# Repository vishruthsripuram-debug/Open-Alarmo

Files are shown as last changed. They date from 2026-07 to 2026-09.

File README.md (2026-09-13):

# Open-Alarmo
**Open Alarmo clock**

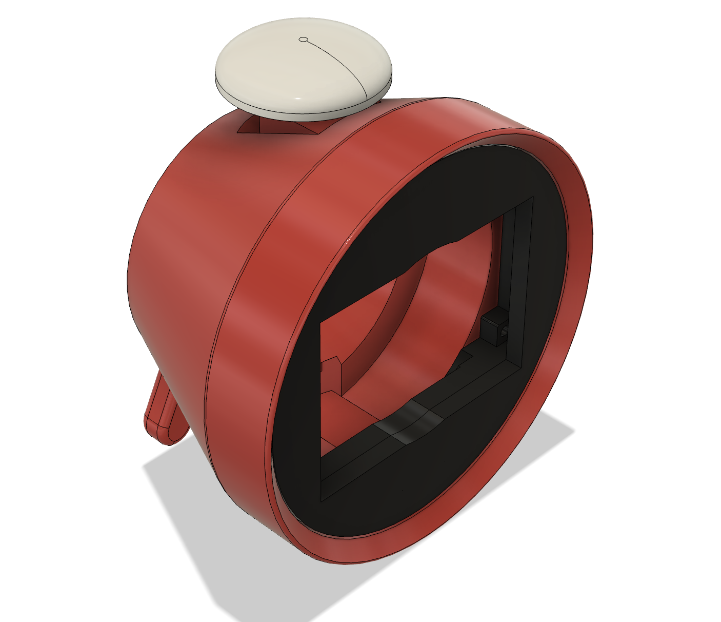
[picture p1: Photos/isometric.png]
Open Alarmo Front View

## design
I wanted to make an alarm clock that would wake me up at morn ing but also do it in a cool way and then an idea popped into my head one from 6 months ago when i saw the Nintendo Alarmo getting released. It was perfect, everything except that t was locked down, made by Nintendo and was too expensive. I set out to build one for a budget of just $20 USD.

It started with inspiration from the Nintendo alarm clock and then i decided to ditch the knob and instead have a web app to control it and set alarms for easier access, control and usability. I decided to keep the nice red design and the black front screen as it looked nice and didn't have any problems with fitting components.

## BOM

| Name | Cost (AUD) | Merchant | Purpose |
| :--- | :--- | :--- | :--- |
| CYD display | 16.79 | Aliexpress | To display the content |
| 1W speaker | 4.70 | aliexpress | to make sound |
| JST 1.25 10cm wire | 1.00 | aliexpress | To connect rotary encoder to CYD |
| KY - 040 rotary encoder | 3.36 | Aliexpress | To act as the dial for the display |
| **Total** | **$25.85** | | |

## Wiring Diagram

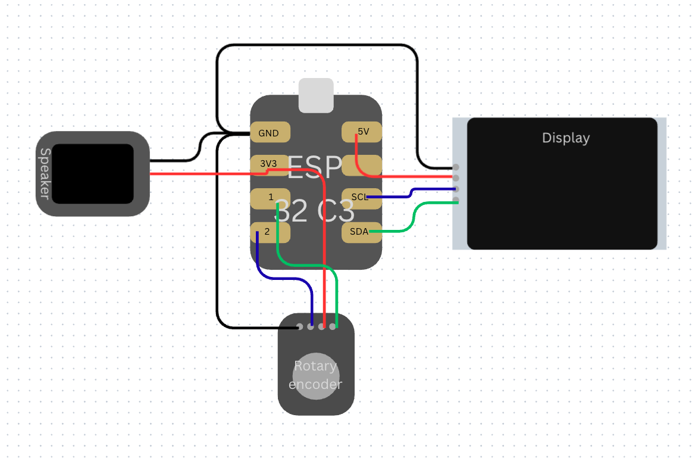
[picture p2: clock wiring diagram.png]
Clock Wiring Diagram


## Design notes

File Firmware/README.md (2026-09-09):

# Bedside Dial Alarm Clock — ESP32 firmware

A bedside alarm clock in the spirit of dedicated "turn the dial" alarm clocks:
big time display, a physical rotary dial on top for everything, and a
speaker for the wake-up chime. Built with an ESP32, a 2.8" SPI TFT
(ILI9341, 240×320), a rotary encoder, and a small speaker.

> Note on sound: the wake-up chime is an original arpeggio I wrote for this
> project, not a reproduction of any commercial device's copyrighted audio.
> Swap `ALARM_MELODY[]` in `src/SoundManager.cpp` for your own tune any time.

---

## 1. Hardware

| Part | Notes |
|---|---|
| ESP32 dev board | Any standard "ESP32-DevKitC"-style board |
| 2.8" SPI TFT, ILI9341 driver, 240×320 | The cheap "2.8 SPI TFT" modules on AliExpress/Amazon are almost all this chip |
| Rotary encoder w/ push button (e.g. EC11) | This is your "dial" — mount it on top of the enclosure |
| Small 8Ω speaker (0.5–1W) + NPN transistor (e.g. 2N2222) + 100–220Ω base resistor | Speaker driven from a PWM pin through a transistor switch |
| Optional: DS3231 RTC breakout | Keeps accurate time through power loss without WiFi. Strongly recommended — see §4 |

### Wiring

**TFT (SPI, ILI9341):**

| TFT pin | ESP32 GPIO |
|---|---|
| VCC | 3V3 |
| GND | GND |
| CS | 15 |
| RESET | 4 |
| DC (RS) | 2 |
| SDI (MOSI) | 23 |
| SCK | 18 |
| SDO (MISO) | 19 |
| LED (backlight) | 27 *(PWM-dimmed)* |

**Rotary encoder (the dial):**

| Encoder pin | ESP32 GPIO |
|---|---|
| A | 33 |
| B | 32 |
| Push button | 26 |
| + / GND | 3V3 / GND |

GPIO 33/32/26 are ordinary GPIOs so the firmware's internal pull-ups work
correctly. Deliberately **not** using GPIO34/35/36/39 for this — those are
input-only pins with no internal pull-up hardware on the ESP32, so
`INPUT_PULLUP` silently fails on them (a common first-build gotcha).

**Speaker (via transistor, simple PWM tone):**

```
GPIO25 --[220Ω]-- Base (2N2222)
Collector -- Speaker(-) 
Emitter -- GND
Speaker(+) -- 3V3
```

**DS3231 RTC (optional but recommended):** SDA → GPIO21, SCL → GPIO22, VCC
→ 3V3, GND → GND.

---

## 2. Software setup

This is a **PlatformIO** project (works in VS Code with the PlatformIO
extension, or via `pio` CLI). Just open the folder — dependencies
(`TFT_eSPI`, `RTClib`) install automatically from `platformio.ini`.

`platformio.ini` pins `platform = espressif32@6.9.0` on purpose — newer
platform releases pull in Arduino-ESP32 core 3.x, which replaced the
`ledcSetup`/`ledcAttachPin`/`ledcWriteTone` calls this firmware uses (for
the backlight PWM and speaker tone) with a different API. If you want to
use a newer core, update those calls in `UIManager::begin()` /
`SoundManager` to the new `ledcAttach(pin, freq, resBits)` /
`ledcWrite(pin, duty)` style first.

If you'd rather use the classic Arduino IDE:
1. Install the `TFT_eSPI` and `RTClib` libraries via Library Manager.
2. Copy the `build_flags` block from `platformio.ini` into your
   `TFT_eSPI/User_Setup.h` as `#define` lines instead (Arduino IDE has no
   `build_flags`, so TFT_eSPI needs its config edited directly in that
   case).
3. Rename `src/main.cpp` to `main.ino` inside a folder of the same name,
   and drop the other `src/*.cpp` + `include/*.h` files alongside it —
   Arduino IDE compiles every `.cpp`/`.h` in the sketch folder together.

### Before you flash

Edit `include/Config.h`:
- `WIFI_SSID` / `WIFI_PASSWORD` — used once at boot to fetch the correct
  time over NTP.
- `GMT_OFFSET_SEC` — currently set to `+10:00` (Sydney standard time).
  Change if you're elsewhere, or if you want DST handled automatically,
  set `DST_OFFSET_SEC` to `3600` during daylight saving.
- `USE_DS3231` — leave at `1` if you wired the RTC module; set to `0` if
  you didn't (the clock will then rely on NTP-synced internal time and
  will lose the correct time on power loss until it reconnects to WiFi).

---

## 3. Using it

**Clock face (home screen):**
- **Turn the dial** → jumps into the Alarms list.
- **Press the dial** → opens the main Menu.

**Main Menu** (New Alarm / Alarms / Brightness / Back):
- Turn to highlight, press to select, hold to go back.

**Alarm list:**
- Turn to highlight an alarm, **press to edit it**, **hold to delete it**.

**Editing an alarm:**
- Turn the dial to change the highlighted field's value (hour → minute →
  repeat → enabled, cycling on each press).
- **Press** moves to the next field.
- **Hold** saves and returns to the list, from any field — so there's no
  separate "Save" button you can accidentally click past.
- The "repeat" field cycles: Once → Everyday → Weekdays → Weekends.

**Brightness screen:** turn to adjust, press or hold to save.

**When an alarm rings:**
- **Turn the dial** (either direction) → snoozes for 9 minutes — this
  mirrors the "twist to snooze" feel of dedicated bedside dial clocks.
- **Press (or hold)** → dismisses it completely.
- Auto-dismisses after 10 minutes if left unattended (see
  `ALARM_RING_TIMEOUT_MIN` in `Config.h`).

Alarms, once set, persist across power loss (stored in flash via
`Preferences`/NVS) — you don't need WiFi or the RTC battery for the
*alarm list* to survive a reboot, only for the *current time* to.

---

## 4. Notes & things you'll likely want to tweak

- **Screen mirrored/rotated wrong?** Change `_tft.setRotation(1)` in
  `UIManager::begin()` (0–3) until it looks right for your enclosure
  orientation.
- **Speaker too quiet/harsh?** `SPEAKER_PIN`'s PWM "tone" through a bare
  transistor is a simple square-wave beeper, not a proper audio amp — for
  actually good speaker quality, swap in a MAX98357A I2S amp module and
  replace `SoundManager`'s `ledcWriteTone` calls with an I2S DAC output.
  The rest of the firmware doesn't care how `SoundManager` makes noise.
- **No DS3231 / don't want to enter WiFi credentials?** The internal
  ESP32 RTC drifts a few seconds a day and has no battery backup — fine
  for a plugged-in clock, but you'll want periodic NTP resync (the
  scaffolding for that is already in `TimeManager::loop()`, just don't
  disconnect WiFi at the end of `TimeManager::begin()` if you want it kept
  alive).
- **Custom per-day repeat schedules** (e.g. "Mon/Wed/Fri only") aren't in
  the UI yet — the data model (`Alarm::daysMask`, one bit per weekday)
  already supports it; `cycleRepeatPreset()` in `main.cpp` only cycles
  through 4 common presets for simplicity. Easy to extend into a
  day-by-day toggle screen if you want it.

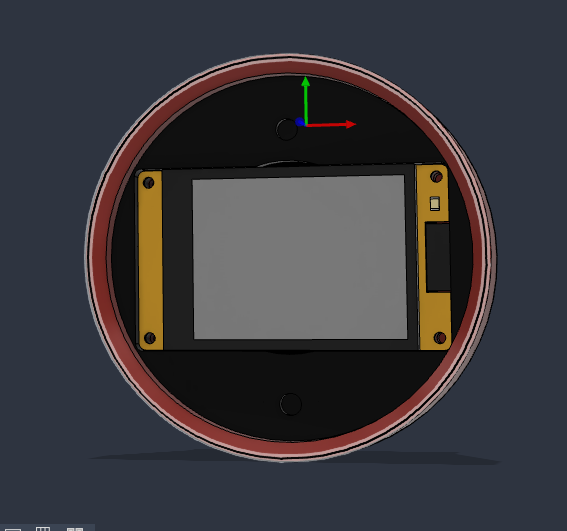
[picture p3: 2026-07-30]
Photos/Front view withoutcover.png

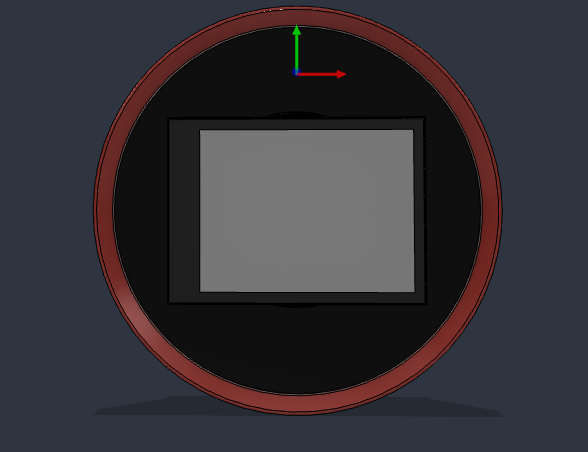
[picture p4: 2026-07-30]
Photos/front_view.png

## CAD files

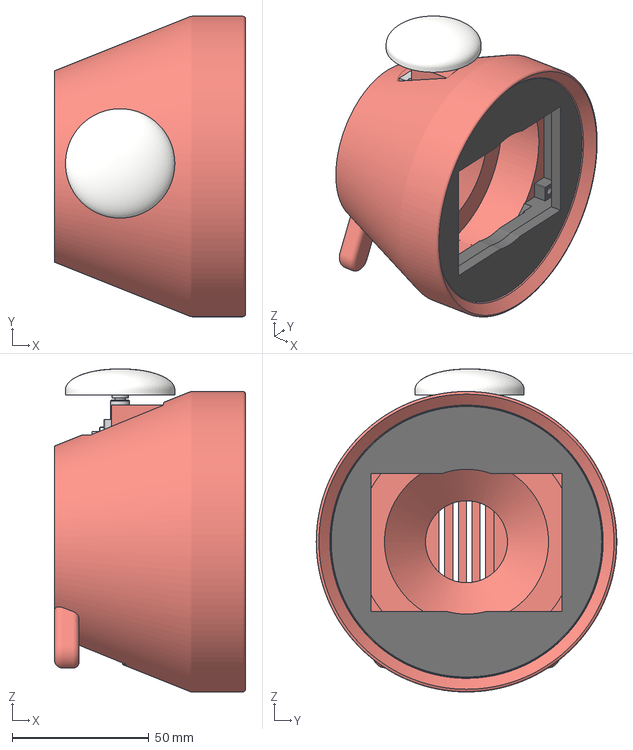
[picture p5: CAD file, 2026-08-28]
CAD files/Print.3mf
70.0 x 110.0 x 118.2 mm

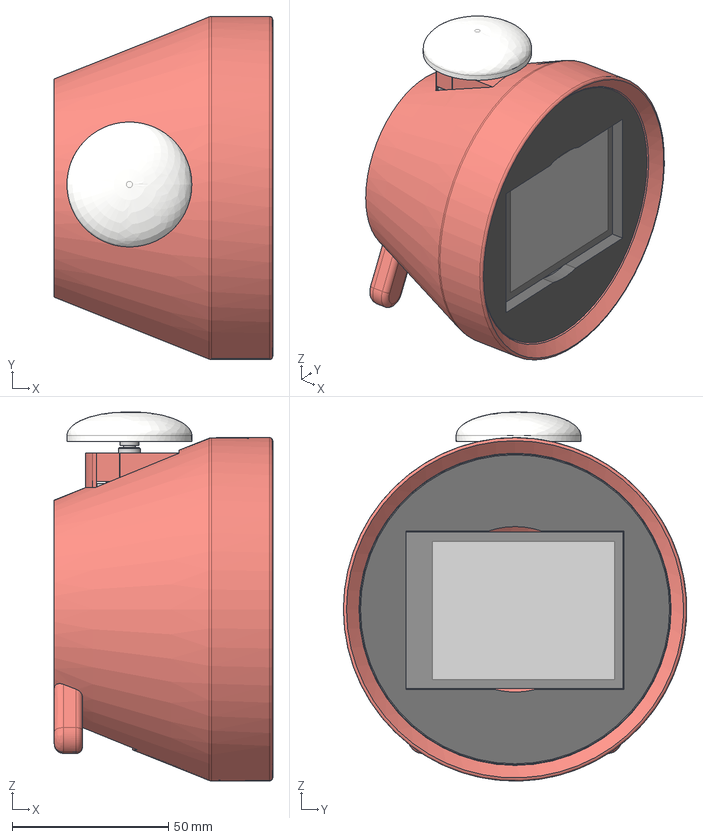
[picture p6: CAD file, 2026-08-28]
CAD files/Alarmo.step
70.0 x 110.0 x 118.2 mm
screen cover
rotary holder
10mm connector x 3
Spkr Connector
switch x 2
Micro SD Card
ESP32 WROOM
Micro USB 5 Pins, Right Angle SMT v1
LDR 21
Encoder KY-040
Rotary dial
Speaker cover plate

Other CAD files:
CAD files/Alarmo.3mf
CAD files/Alarmo.f3z

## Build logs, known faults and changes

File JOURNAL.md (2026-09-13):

---
title: "Open-Alarmo"
author: "Vishruth-S"
description: "An open source easy to build Alarm clock"
created_at: "2026-07-23"
---
# July 24: Planning project
**I started planning my project**
I wanted to make an alarm clock that would wake me up at morn ing but also do it in a cool way and then an idea popped into my head one from 6 months ago when i saw the Nintendo Alarmo getting released. It was perfect, everything except that t was locked down, made by Nintendo and was too expensive. I set out to build one for a budget of just $20 USD.

It started with inspiration from the Nintendo alarm clock and then i decided to ditch the knob and instead have a web app to control it and set alarms for easier access, control and usability. I decided to keep the nice red design and the black front screen as it looked nice and didn't have any problems with fitting components.


**Total time spent: 2.5 hours**

# July 24: CAD
I recorded my CAD time using Hackatime In this Cad session i designed and started to build the main frame of the clock it has a similar concave barrel shape but is more curved at the ends to offer a slightly nicer aesthetic. I decided to build it in 2 parts, the main body and the screen holder, the screen holder was by far the most complex part about the design, first i had to design it to fit smoothly without too many bumps and then i had to figure out a way to attach it to the main body. I originally though about screws but realized that screws may protrude outside of the main body and look ugly so i decided to design a twist lock mechanism using 2 fingers that twist into the main body. this removes the need fro screws and simplifies the assembly.
Inside view

**Total time spent: 4 hours**

# July 25: Shopping for components
Went shopping for the components
I found a rotary encoder that would connect to the CYD via a jst connector

I found everything on Aliexpress as it was cheapest and found the versions that had models available on Grabcad so design would be easier.

The updated BOM
also updated on Github readme

| Name | Cost (AUD) | Merchant | Purpose |
| :--- | :--- | :--- | :--- |
| CYD display | 16.79 | Aliexpress | To display the content |
| 1W speaker | 4.70 | aliexpress | to make sound |
| JST 1.25 10cm wire | 1.00 | Aliexpress | To connect rotary encoder to CYD |
| KY - 040 rotary encoder | 3.36 | Aliexpress | To act as the dial for the display |
| **Total** | **$25.85** | | |

Screenshot 2026-07-29 at 12 32 48 PM

**Total time spent: 3 hours**

# July 27: Redesign for CYD
I changed the design to accommodate a 2.8" touchscreen also more commonly known as the CYD which is a readily available, no solder low profile alternative tp using a TFT display and separate ESP 32 board. I removed the old twist lock mechanism in favor of the good old simple m3 screw which fits better into the design and is cleaner to look at, the front cover plate not has 2 options to attach. The first is press fit where you press fit it onto the display and the second is magnets, magnets are the preferred route but are more expensive so i decided to include a simpler alternative.
Front view withoutcover

**Total time spent: 5 hours**

# July 30: CAD
I added the mount for the rotary encoder and developed the front magnetic cover for the screen. The front magnetic cover is going to be black PLA to blend into the screen when it is turned off. When adding the front cover plate i had to decide what method of attachment i want to use, i wanted it to be easily removable for future upgrades and repairs but also wanted it to be stable and strong. Eventually after some thinking and trying out twist lock ideas i decided on using some strong 6x3 neodymium magnets fairly priced at just 33 C per magnet and only needing 2 would add only 66 cents to the project. After i finished back i went back to remedy my previous failure of a design for the rotary encoder mount, it was clunky, ugly and didn't match at all, so i decided to change it. I first deleted all of the old things in the timeline and restarted with a blank slate, i made an offset plane and extruded a rectangle onto it to create the platform and base. off of this platform i made some forms that would hold it in place and added a screw hole. The whole board just slides in and connects using a JST connector on the back of the CYD which i left a space for on the disc that is inserted into the main body. I then positioned the board and designed the back plate so then it would match perfectly and slide into the grommett there previously.
magnet
Without screen cover
Screenshot 2026-07-30 at 6 12 59 PM

**Total time spent: 3 hours**

# July 31: CAD
I designed the rotary dial cap, this is similar to the dial used to control the Nintendo Alarmo, although my variant will be touchscreen. The dial can be used to set alarms, timers and other time related activities, the dial can also be used to play games on the clock, it is a fun feature similar to the playdate. I had to figure out how to use a different type of filet, an asymmetrical fillet to get the desired shape. The clock design is now almost complete the last remaining feature is the speaker hole and the haptic motor for a satisfying feel everytime the wheel is turned.

Front view
Rotary dial
rotary encoder

**Total time spent: 3 hours**

# July 31: CAD: adding speaker grille and expanding USB port
I added the final touch which was the space for the speaker on the back of the device. The USB port expansion was a simple sketch and cut of the main body. The speaker grille is removable and vertical which i thought looked nice.
Speaker hole
**Total time spent: 1.5 hours**

# 09/9/2026 - I developed the code and editing software for the macropad

**Time spent:** 1.5h
I used claude to vibecode the firmware for the clock. This is just a sample firmware so i made it not apply to any pins yet however soon i can add the pins once I buy all the components and start building.
The clock has multiple files can have images uploaded to it and can ring an alarm to wake someone up, i also added animated icons and made a webpage for the same purpose.
work screenshot

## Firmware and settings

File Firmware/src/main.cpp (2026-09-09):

// =====================================================================
//  Nintendo-Alarmo-style ESP32 alarm clock
//
//  Hardware: ESP32 dev board + 2.8" SPI TFT (ILI9341) + small speaker
//            driven through a transistor + a rotary encoder w/ push
//            button mounted on top as the main control dial.
//
//  Interaction model (mirrors the "turn the dial" feel of a dedicated
//  bedside alarm clock):
//    Clock face  : rotate -> jump into Alarm List | click -> Main Menu
//    Main Menu   : rotate -> highlight | click -> select | hold -> back
//    Alarm List  : rotate -> highlight | click -> edit | hold -> delete
//    Edit Alarm  : rotate -> change focused field | click -> next field
//                  hold -> save & return to list
//    Brightness  : rotate -> adjust | click/hold -> save & back
//    Ringing     : rotate (either way) -> snooze | click/hold -> dismiss
//
//  See README.md for wiring and library setup.
// =====================================================================
#include <Arduino.h>
#include "Config.h"
#include "UIManager.h"
#include "RotaryInput.h"
#include "SoundManager.h"
#include "AlarmManager.h"
#include "TimeManager.h"

// ---------------------------------------------------------------------
// globals
// ---------------------------------------------------------------------
UIManager     ui;
RotaryInput   dial;
SoundManager  sound;
AlarmManager  alarms;
TimeManager   clock_;

enum class AppState { CLOCK, MENU, ALARM_LIST, EDIT_ALARM, BRIGHTNESS, RINGING };
AppState state = AppState::CLOCK;

MenuItem  menuSelect = MenuItem::NEW_ALARM;
uint8_t   alarmListSelect = 0;

EditField editField = EditField::HOUR;
uint8_t   editingIndex = 0;
bool      isNewAlarm = false;

int       ringingIndex = -1;   // index into alarms[], or -1 if snooze-triggered w/ no stable index
Alarm     ringingAlarmSnapshot;
uint32_t  ringingAnimStart = 0;

uint8_t   pendingBrightness = DEFAULT_BRIGHTNESS;

uint32_t  lastUiTickMs = 0;

// ---------------------------------------------------------------------
// helpers
// ---------------------------------------------------------------------
static const char *repeatLabelFor(uint8_t mask) {
    if (mask == 0)          return "Once";
    if (mask == 0x7F)       return "Everyday";
    if (mask == 0b0111110)  return "Weekdays";
    if (mask == 0b1000001)  return "Weekends";
    return "Custom";
}

// Finds the soonest upcoming enabled alarm (today or later this week) for
// the clock-face "Next" chip. Returns false if none are enabled.
static bool findNextAlarm(uint8_t nowWday, uint8_t nowH, uint8_t nowM,
                           uint8_t &outH, uint8_t &outM, const char *&outRepeat) {
    int bestDelta = INT32_MAX;
    int bestIdx = -1;
    int nowMin = nowH * 60 + nowM;

    for (uint8_t i = 0; i < alarms.count(); i++) {
        Alarm &a = alarms.at(i);
        if (!a.enabled) continue;
        int alarmMin = a.hour * 60 + a.minute;

        for (int d = 0; d < 7; d++) {
            uint8_t wday = (nowWday + d) % 7;
            // one-off (daysMask == 0) alarms only ever count for "today, if still ahead"
            if (a.daysMask == 0) {
                if (d > 0) continue;
            } else if (!(a.daysMask & (1 << wday))) {
                continue;
            }

            int delta = d * 1440 + alarmMin - nowMin;
            if (delta < 0) continue;
            if (delta < bestDelta) {
                bestDelta = delta;
                bestIdx = i;
            }
        }
    }

    if (bestIdx < 0) return false;
    outH = alarms.at(bestIdx).hour;
    outM = alarms.at(bestIdx).minute;
    outRepeat = repeatLabelFor(alarms.at(bestIdx).daysMask);
    return true;
}

static void enterRinging(int idx, const Alarm &snapshot) {
    state = AppState::RINGING;
    ringingIndex = idx;
    ringingAlarmSnapshot = snapshot;
    ringingAnimStart = millis();
    sound.startAlarm();
    ui.forceFullRedraw();
}

static void cycleRepeatPreset(Alarm &a, int direction) {
    static const uint8_t presets[] = {0x00, 0x7F, 0b0111110, 0b1000001};
    const int n = 4;
    int cur = 0;
    for (int i = 0; i < n; i++) if (presets[i] == a.daysMask) { cur = i; break; }
    cur = (cur + direction % n + n) % n;
    a.daysMask = presets[cur];
}

// ---------------------------------------------------------------------
// setup / loop
// ---------------------------------------------------------------------
void setup() {
    Serial.begin(115200);

    ui.begin();
    dial.begin();
    sound.begin();
    alarms.begin();
    clock_.begin();     // connects WiFi briefly to sync time, then (by default) drops it

    pendingBrightness = ui.brightness();
    ui.forceFullRedraw();
}

void loop() {
    DialEvent ev = dial.poll();
    struct tm t = clock_.now();
    clock_.loop();

    // ---- global: alarm triggering (checked once per minute, highest priority) ----
    if (state != AppState::RINGING && clock_.minuteChanged()) {
        int idx = alarms.checkTrigger(t.tm_wday, t.tm_hour, t.tm_min);
        if (idx == -2) {
            // snoozed alarm coming back due -- reuse last snapshot's label/time for display
            enterRinging(-1, ringingAlarmSnapshot);
        } else if (idx >= 0) {
            enterRinging(idx, alarms.at(idx));
        }
    }

    switch (state) {
        // -----------------------------------------------------------
        case AppState::CLOCK: {
            if (ev.ticks != 0) {
                state = AppState::ALARM_LIST;
                alarmListSelect = (uint8_t)constrain((int)alarmListSelect + ev.ticks, 0, alarms.count() - 1);
                sound.tickClick();
                ui.forceFullRedraw();
            } else if (ev.clicked) {
                state = AppState::MENU;
                menuSelect = MenuItem::NEW_ALARM;
                sound.confirmBeep();
                ui.forceFullRedraw();
            } else {
                uint8_t nh = 0, nm = 0; const char *nr = "";
                bool has = findNextAlarm(t.tm_wday, t.tm_hour, t.tm_min, nh, nm, nr);
                ui.drawClock(t, clock_.wifiConnected(), has, nh, nm, nr);
            }
            break;
        }

        // -----------------------------------------------------------
        case AppState::MENU: {
            if (ev.ticks != 0) {
                int n = (int)MenuItem::COUNT;
                int cur = ((int)menuSelect + ev.ticks) % n;
                if (cur < 0) cur += n;
                menuSelect = (MenuItem)cur;
                sound.tickClick();
            }
            if (ev.clicked) {
                sound.confirmBeep();
                switch (menuSelect) {
                    case MenuItem::NEW_ALARM: {
                        // find a free (disabled) slot, else reuse slot 0
                        int freeIdx = 0;
                        for (uint8_t i = 0; i < alarms.count(); i++) {
                            if (!alarms.at(i).enabled) { freeIdx = i; break; }
                        }
                        editingIndex = freeIdx;
                        isNewAlarm = true;
                        Alarm &a = alarms.at(editingIndex);
                        a = Alarm{};           // reset to sensible default
                        a.enabled = true;
                        strncpy(a.label, "Alarm", ALARM_LABEL_LEN);
                        editField = EditField::HOUR;
                        state = AppState::EDIT_ALARM;
                        break;
                    }
                    case MenuItem::ALARMS:
                        state = AppState::ALARM_LIST;
                        alarmListSelect = 0;
                        break;
                    case MenuItem::BRIGHTNESS:
                        pendingBrightness = ui.brightness();
                        state = AppState::BRIGHTNESS;
                        break;
                    case MenuItem::BACK:
                    default:
                        state = AppState::CLOCK;
                        break;
                }
                ui.forceFullRedraw();
            }
            if (ev.longPressed) {
                sound.backBeep();
                state = AppState::CLOCK;
                ui.forceFullRedraw();
            }
            if (state == AppState::MENU) ui.drawMenu(menuSelect);
            break;
        }

        // -----------------------------------------------------------
        case AppState::ALARM_LIST: {
            if (ev.ticks != 0) {
                alarmListSelect = (uint8_t)constrain((int)alarmListSelect + ev.ticks, 0, alarms.count() - 1);
                sound.tickClick();
            }
            if (ev.clicked) {
                editingIndex = alarmListSelect;
                isNewAlarm = false;
                editField = EditField::HOUR;
                sound.confirmBeep();
                state = AppState::EDIT_ALARM;
                ui.forceFullRedraw();
                break;
            }
            if (ev.longPressed) {
                // delete the selected alarm
                alarms.at(alarmListSelect) = Alarm{};
                alarms.save();
                sound.backBeep();
                ui.forceFullRedraw();
            }
            if (state == AppState::ALARM_LIST) ui.drawAlarmList(alarms, alarmListSelect);
            break;
        }

        // -----------------------------------------------------------
        case AppState::EDIT_ALARM: {
            Alarm &a = alarms.at(editingIndex);

            if (ev.ticks != 0) {
                switch (editField) {
                    case EditField::HOUR:
                        a.hour = (uint8_t)(((int)a.hour + ev.ticks) % 24 + 24) % 24;
                        break;
                    case EditField::MINUTE:
                        a.minute = (uint8_t)(((int)a.minute + ev.ticks) % 60 + 60) % 60;
                        break;
                    case EditField::REPEAT:
                        cycleRepeatPreset(a, ev.ticks > 0 ? 1 : -1);
                        break;
                    case EditField::ENABLED:
                        a.enabled = !a.enabled;
                        break;
                    default: break;
                }
                sound.tickClick();
            }
            if (ev.clicked) {
                int next = ((int)editField + 1) % (int)EditField::COUNT;
                editField = (EditField)next;
                sound.tickClick();
            }
            if (ev.longPressed) {
                alarms.save();
                sound.confirmBeep();
                state = AppState::ALARM_LIST;
                alarmListSelect = editingIndex;
                ui.forceFullRedraw();
                break;
            }
            if (state == AppState::EDIT_ALARM) ui.drawEditAlarm(a, editField, isNewAlarm);
            break;
        }

        // -----------------------------------------------------------
        case AppState::BRIGHTNESS: {
            if (ev.ticks != 0) {
                int v = (int)pendingBrightness + ev.ticks * 8;
                pendingBrightness = (uint8_t)constrain(v, 10, 255);
                ui.setBrightness(pendingBrightness);
            }
            if (ev.clicked || ev.longPressed) {
                sound.confirmBeep();
                state = AppState::MENU;
                ui.forceFullRedraw();
                break;
            }
            if (state == AppState::BRIGHTNESS) ui.drawBrightnessScreen(pendingBrightness);
            break;
        }

        // -----------------------------------------------------------
        case AppState::RINGING: {
            sound.update();

            if (ev.ticks != 0) {
                // twist the dial to snooze -- classic bedside-clock gesture
                sound.stopAlarm();
                alarms.armSnooze(t.tm_hour, t.tm_min);
                sound.confirmBeep();
                state = AppState::CLOCK;
                ui.forceFullRedraw();
                break;
            }
            if (ev.clicked || ev.longPressed) {
                sound.stopAlarm();
                alarms.clearSnooze();
                sound.backBeep();
                state = AppState::CLOCK;
                ui.forceFullRedraw();
                break;
            }

            // safety timeout so it can never ring forever unattended
            if (millis() - ringingAnimStart > (uint32_t)ALARM_RING_TIMEOUT_MIN * 60UL * 1000UL) {
                sound.stopAlarm();
                alarms.clearSnooze();
                state = AppState::CLOCK;
                ui.forceFullRedraw();
                break;
            }

            ui.drawRinging(ringingAlarmSnapshot, millis() - ringingAnimStart, true);
            break;
        }
    }

    // Ringing screen animates continuously; everything else can idle a
    // touch to keep CPU/power reasonable without feeling laggy.
    if (state != AppState::RINGING) {
        delay(15);
    }
}

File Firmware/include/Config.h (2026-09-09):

#pragma once
#include <Arduino.h>

// =====================================================================
// WIFI / TIME
// =====================================================================
#define WIFI_SSID           "YOUR_WIFI_SSID"
#define WIFI_PASSWORD       "YOUR_WIFI_PASSWORD"
#define NTP_SERVER          "pool.ntp.org"
#define GMT_OFFSET_SEC      (10 * 3600)      // Sydney standard time, adjust as needed
#define DST_OFFSET_SEC      0                 // set 3600 during AEDT if you want auto DST
#define WIFI_CONNECT_TIMEOUT_MS 8000

// =====================================================================
// ROTARY DIAL  (quadrature encoder + push button, mounted on top)
// =====================================================================
// NOTE: deliberately avoiding GPIO34/35/36/39 here -- those are
// input-only pins on the ESP32 with no internal pull-up/pull-down
// hardware, so INPUT_PULLUP silently does nothing on them. 33/32/26
// are regular GPIOs and work correctly with INPUT_PULLUP.
#define ENC_PIN_A            33
#define ENC_PIN_B            32
#define ENC_PIN_BTN          26
#define ENC_BTN_ACTIVE_LOW  true
#define ENC_LONG_PRESS_MS   600
#define ENC_DETENTS_PER_CLICK 4  // most cheap encoders emit 4 edges per detent

// =====================================================================
// SPEAKER  (piezo / small speaker driven through a transistor from a
//           PWM-capable GPIO -- see README wiring section)
// =====================================================================
#define SPEAKER_PIN          25
#define SPEAKER_LEDC_CHANNEL 0
#define SPEAKER_LEDC_RES_BITS 10

// =====================================================================
// TOUCH-FREE BACKLIGHT DIMMING (PWM)
// =====================================================================
#define BL_LEDC_CHANNEL      1
#define BL_LEDC_RES_BITS     8
#define BL_LEDC_FREQ_HZ      5000
#define DEFAULT_BRIGHTNESS   200   // 0-255

// =====================================================================
// RTC
// =====================================================================
#define USE_DS3231            1   // 1 = battery-backed external RTC present, 0 = NTP/internal only
#define I2C_SDA               21
#define I2C_SCL               22

// =====================================================================
// ALARMS
// =====================================================================
#define MAX_ALARMS            8
#define SNOOZE_MINUTES        9
#define ALARM_LABEL_LEN        20
#define ALARM_RING_TIMEOUT_MIN 10   // auto-stop a ringing alarm after this long

// =====================================================================
// COLOUR PALETTE  (warm cream body / soft orange accent, inspired by
// the look of dedicated bedside alarm clocks -- not any copyrighted
// artwork or assets)
// =====================================================================
#define COL_BG           0xFBE0   // warm cream background
#define COL_BG_DARK       0x18E3   // used behind the "ringing" screen
#define COL_CARD          0xFFFF
#define COL_CARD_SHADOW   0xE73C
#define COL_ACCENT        0xFB40   // warm orange
#define COL_ACCENT_DARK   0xC300
#define COL_TEXT          0x2104   // near-black
#define COL_TEXT_MUTED    0x8C71
#define COL_GOOD          0x3E67   // soft green (enabled / connected)
#define COL_WARN          0xFA00

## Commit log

2026-07-24 Update README with project details and BOM
    Expanded project description and added BOM table.
2026-07-25 Revise BOM with new components and pricing
    Updated the BOM section with new components and costs.
2026-07-30 Update JOURNAL.md with project planning and design notes
    Added detailed project planning and updates on CAD design, shopping for components, and redesign for CYD touchscreen.
2026-09-13 Update wiring diagram image in README
2026-09-13 Fix image reference in README for wiring diagram
